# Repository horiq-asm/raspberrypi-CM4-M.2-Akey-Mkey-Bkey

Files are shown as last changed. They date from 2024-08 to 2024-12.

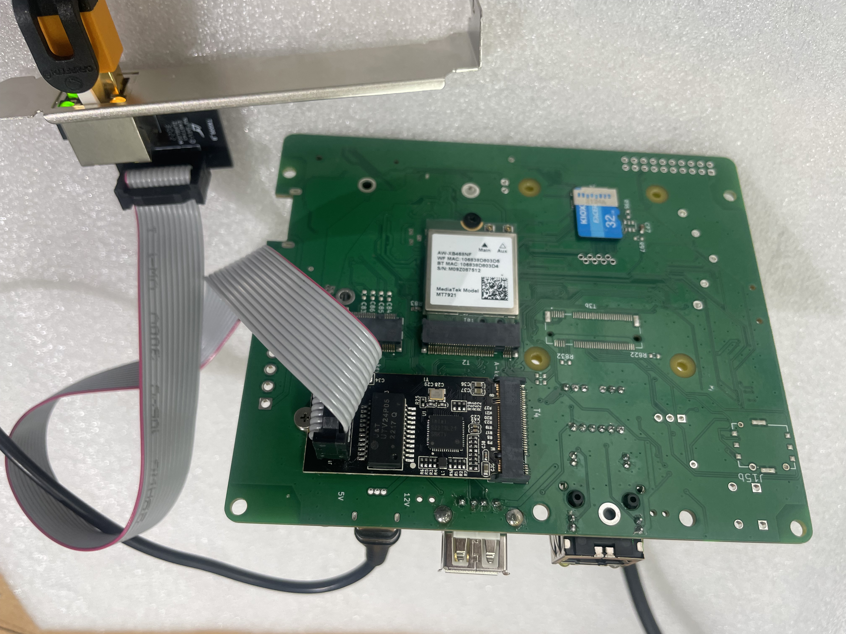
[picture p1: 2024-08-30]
IMG_6215.jpg

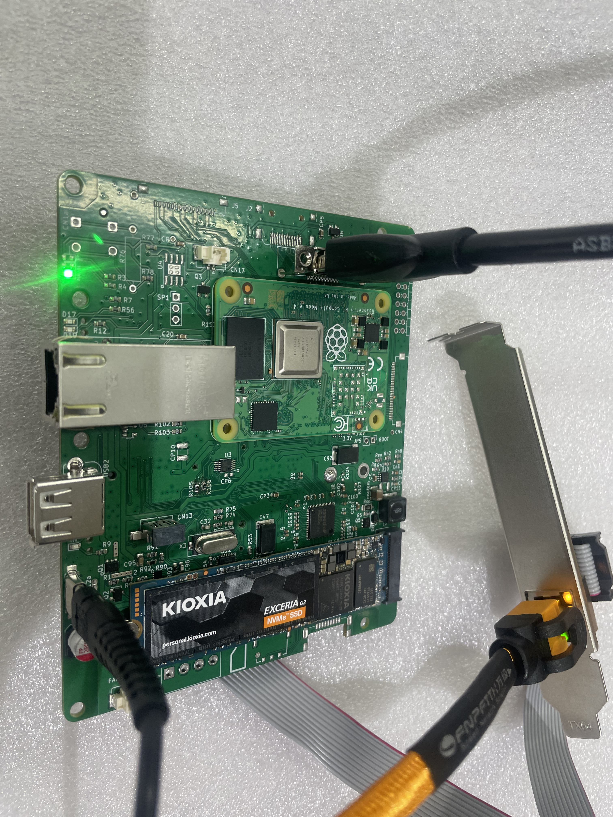
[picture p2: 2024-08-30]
IMG_6214.jpg

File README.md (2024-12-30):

boot CM5 via NVMe behind PCIe switch !!!<br>
新たに入手したCM5を入れるとNVMeからbootできました。
2024年12月クリスマスプレゼントです。<br>
youtube で動作画像ご覧ください　https://youtu.be/MDhNWYu6bRE



# raspberrypi-CM4-M.2-Akey-Mkey-Bkey
raspberypi　CM4にpcie swich を載せてM.2基板を複数動作できる基板を作成しました。
wifi6　１G　2.5Gのnicが動きます。
MkeyにはNVMeを搭載しています。

$ lspci<br>
00:00.0 PCI bridge: Broadcom Inc. and subsidiaries BCM2711 PCIe Bridge (rev 20)<br>
01:00.0 PCI bridge: ASMedia Technology Inc. ASM1184e 4-Port PCIe x1 Gen2 Packet Switch<br>
02:01.0 PCI bridge: ASMedia Technology Inc. ASM1184e 4-Port PCIe x1 Gen2 Packet Switch<br>
02:03.0 PCI bridge: ASMedia Technology Inc. ASM1184e 4-Port PCIe x1 Gen2 Packet Switch<br>
02:05.0 PCI bridge: ASMedia Technology Inc. ASM1184e 4-Port PCIe x1 Gen2 Packet Switch<br>
02:07.0 PCI bridge: ASMedia Technology Inc. ASM1184e 4-Port PCIe x1 Gen2 Packet Switch<br>
03:00.0 Network controller: MEDIATEK Corp. MT7921 802.11ax PCI Express Wireless Network Adapter<br>
04:00.0 Non-Volatile memory controller: KIOXIA Corporation NVMe SSD (rev 01)<br>
05:00.0 Ethernet controller: Intel Corporation Ethernet Controller I226-V (rev 04)<br>
<br>
$ ethtool eth1<br>
Settings for eth1:<br>
        Supported ports: [ TP ]<br>
        Supported link modes:   10baseT/Half 10baseT/Full<br>
                                100baseT/Half 100baseT/Full<br>
                                1000baseT/Full<br>
                                2500baseT/Full<br>
        Supported pause frame use: Symmetric<br>
        Supports auto-negotiation: Yes<br>
        Supported FEC modes: Not reported<br>
        Advertised link modes:  10baseT/Half 10baseT/Full<br>
                                100baseT/Half 100baseT/Full<br>
                                1000baseT/Full<br>
                                2500baseT/Full<br>
        Advertised pause frame use: Symmetric<br>
        Advertised auto-negotiation: Yes<br>
        Advertised FEC modes: Not reported<br>
        Speed: 2500Mb/s<br>
        Duplex: Full<br>
        Auto-negotiation: on<br>
        Port: Twisted Pair<br>
        PHYAD: 0<br>
        Transceiver: internal<br>
        MDI-X: off (auto)<br>
netlink error: Operation not permitted<br>
        Current message level: 0x00000007 (7)<br>
                               drv probe link<br>
        Link detected: yes<br>
<br>
<br>
$ nmcli d s<br>
DEVICE         TYPE      STATE                   CONNECTION<br>
wlan0          wifi      connected               WIFI_AP<br>
eth1           ethernet  connected               Wired connection 2<br>
lo             loopback  connected (externally)  lo<br>
p2p-dev-wlan0  wifi-p2p  disconnected            --<br>
eth0           ethernet  unavailable             --<br>
<br>
%%%<br>
Network controller: MEDIATEK Corp. MT7921 802.11ax PCI Express Wireless Network Adapter<br>
のためには　　/boot/firmware/config.txt　　に下記の変更が必要です。<br>
[all]<br>
dtparam=pciex1<br>
dtoverlay=pcie-32bit-dma<br>
<br>
<br>
$ iw phy0 info<br>
Wiphy phy0<br>
        wiphy index: 0<br>
        max # scan SSIDs: 4<br>
        max scan IEs length: 482 bytes<br>
        max # sched scan SSIDs: 10<br>
        max # match sets: 16<br>
        Retry short limit: 7<br>
        Retry long limit: 4<br>
        Coverage class: 0 (up to 0m)<br>
        Device supports AP-side u-APSD.<br>
        Device supports T-DLS.<br>
        Supported Ciphers:<br>
                * WEP40 (00-0f-ac:1)<br>
                * WEP104 (00-0f-ac:5)<br>
                * TKIP (00-0f-ac:2)<br>
                * CCMP-128 (00-0f-ac:4)<br>
                * CCMP-256 (00-0f-ac:10)<br>
                * GCMP-128 (00-0f-ac:8)<br>
                * GCMP-256 (00-0f-ac:9)<br>
                * CMAC (00-0f-ac:6)<br>
                * CMAC-256 (00-0f-ac:13)<br>
                * GMAC-128 (00-0f-ac:11)<br>
                * GMAC-256 (00-0f-ac:12)<br>
        Available Antennas: TX 0x3 RX 0x3<br>
        Configured Antennas: TX 0x3 RX 0x3<br>
        Supported interface modes:<br>
                 * managed<br>
                 * AP<br>
                 * AP/VLAN<br>
                 * monitor<br>
                 * P2P-client<br>
                 * P2P-GO<br>
        Band 1:<br>
                Capabilities: 0x9ff<br>
                        RX LDPC<br>
                        HT20/HT40<br>
                        SM Power Save disabled<br>
                        RX Greenfield<br>
                        RX HT20 SGI<br>
                        RX HT40 SGI<br>
                        TX STBC<br>
                        RX STBC 1-stream<br>
                        Max AMSDU length: 7935 bytes<br>
                        No DSSS/CCK HT40<br>
                Maximum RX AMPDU length 65535 bytes (exponent: 0x003)<br>
                Minimum RX AMPDU time spacing: No restriction (0x00)<br>
                HT TX/RX MCS rate indexes supported: 0-15<br>
                HE Iftypes: managed<br>
                        HE MAC Capabilities (0x08011a000040):<br>
                                +HTC HE Supported<br>
                                Trigger Frame MAC Padding Duration: 2<br>
                                OM Control<br>
                                Maximum A-MPDU Length Exponent: 3<br>
                                A-MSDU in A-MPDU<br>
                        HE PHY Capabilities: (0x2270ce120dc0b306423f00):<br>
                                HE40/2.4GHz<br>
                                242 tone RUs/2.4GHz<br>
                                Device Class: 1<br>
                                LDPC Coding in Payload<br>
                                HE SU PPDU with 1x HE-LTF and 0.8us GI<br>
                                NDP with 4x HE-LTF and 3.2us GI<br>
                                STBC Tx <= 80MHz<br>
                                STBC Rx <= 80MHz<br>
                                Full Bandwidth UL MU-MIMO<br>
                                Partial Bandwidth UL MU-MIMO<br>
                                DCM Max Constellation: 2<br>
                                DCM Max Constellation Rx: 2<br>
                                SU Beamformee<br>
                                Beamformee STS <= 80Mhz: 3<br>
                                Ng = 16 SU Feedback<br>
                                Ng = 16 MU Feedback<br>
                                Codebook Size SU Feedback<br>
                                Codebook Size MU Feedback<br>
                                Triggered CQI Feedback<br>
                                Partial Bandwidth Extended Range<br>
                                PPE Threshold Present<br>
                                Power Boost Factor ar<br>
                                HE SU PPDU & HE PPDU 4x HE-LTF 0.8us GI<br>
                                20MHz in 40MHz HE PPDU 2.4GHz<br>
                                DCM Max BW: 1<br>
                                Longer Than 16HE SIG-B OFDM Symbols<br>
                                Non-Triggered CQI Feedback<br>
                                TX 1024-QAM<br>
                                RX 1024-QAM<br>
                                RX Full BW SU Using HE MU PPDU with Compression SIGB<br>
                                RX Full BW SU Using HE MU PPDU with Non-Compression SIGB<br>
                        HE RX MCS and NSS set <= 80 MHz<br>
                                1 streams: MCS 0-11<br>
                                2 streams: MCS 0-11<br>
                                3 streams: not supported<br>
                                4 streams: not supported<br>
                                5 streams: not supported<br>
                                6 streams: not supported<br>
                                7 streams: not supported<br>
                                8 streams: not supported<br>
                        HE TX MCS and NSS set <= 80 MHz<br>
                                1 streams: MCS 0-11<br>
                                2 streams: MCS 0-11<br>
                                3 streams: not supported<br>
                                4 streams: not supported<br>
                                5 streams: not supported<br>
                                6 streams: not supported<br>
                                7 streams: not supported<br>
                                8 streams: not supported<br>
                        PPE Threshold 0x39 0x1c 0xc7 0x71 0x1c 0x07<br>
                EHT Iftypes: managed<br>
                        EHT MAC Capabilities (0x0000):<br>
                        EHT PHY Capabilities: (0x0000000000000000):<br>
                        EHT MCS/NSS: (0x):<br>
                        EHT bw=20 MHz, max NSS for MCS 0-7: Rx=0, Tx=0<br>
                        EHT bw=20 MHz, max NSS for MCS 8-9: Rx=0, Tx=0<br>
                        EHT bw=20 MHz, max NSS for MCS 10-11: Rx=0, Tx=0<br>
                        EHT bw=20 MHz, max NSS for MCS 12-13: Rx=0, Tx=0<br>
                HE Iftypes: AP<br>
                        HE MAC Capabilities (0x00011a081044):<br>
                                +HTC HE Supported<br>
                                BSR<br>
                                OM Control<br>
                                Maximum A-MPDU Length Exponent: 3<br>
                                BQR<br>
                                A-MSDU in A-MPDU<br>
                                OM Control UL MU Data Disable RX<br>
                        HE PHY Capabilities: (0x0220ce120000a000000c00):<br>
                                HE40/2.4GHz<br>
                                LDPC Coding in Payload<br>
                                NDP with 4x HE-LTF and 3.2us GI<br>
                                STBC Tx <= 80MHz<br>
                                STBC Rx <= 80MHz<br>
                                Full Bandwidth UL MU-MIMO<br>
                                Partial Bandwidth UL MU-MIMO<br>
                                DCM Max Constellation: 2<br>
                                DCM Max Constellation Rx: 2<br>
                                Partial Bandwidth Extended Range<br>
                                PPE Threshold Present<br>
                                TX 1024-QAM<br>
                                RX 1024-QAM<br>
                        HE RX MCS and NSS set <= 80 MHz<br>
                                1 streams: MCS 0-11<br>
                                2 streams: MCS 0-11<br>
                                3 streams: not supported<br>
                                4 streams: not supported<br>
                                5 streams: not supported<br>
                                6 streams: not supported<br>
                                7 streams: not supported<br>
                                8 streams: not supported<br>
                        HE TX MCS and NSS set <= 80 MHz<br>
                                1 streams: MCS 0-11<br>
                                2 streams: MCS 0-11<br>
                                3 streams: not supported<br>
                                4 streams: not supported<br>
                                5 streams: not supported<br>
                                6 streams: not supported<br>
                                7 streams: not supported<br>
                                8 streams: not supported<br>
                        PPE Threshold 0x39 0x1c 0xc7 0x71 0x1c 0x07<br>
                EHT Iftypes: AP<br>
                        EHT MAC Capabilities (0x0000):<br>
                        EHT PHY Capabilities: (0x0000000000000000):<br>
                        EHT MCS/NSS: (0x):<br>
                        EHT bw=20 MHz, max NSS for MCS 0-7: Rx=0, Tx=0<br>
                        EHT bw=20 MHz, max NSS for MCS 8-9: Rx=0, Tx=0<br>
                        EHT bw=20 MHz, max NSS for MCS 10-11: Rx=0, Tx=0<br>
                        EHT bw=20 MHz, max NSS for MCS 12-13: Rx=0, Tx=0<br>
                Bitrates (non-HT):<br>
                        * 1.0 Mbps (short preamble supported)<br>
                        * 2.0 Mbps (short preamble supported)<br>
                        * 5.5 Mbps (short preamble supported)<br>
                        * 11.0 Mbps (short preamble supported)<br>
                        * 6.0 Mbps<br>
                        * 9.0 Mbps<br>
                        * 12.0 Mbps<br>
                        * 18.0 Mbps<br>
                        * 24.0 Mbps<br>
                        * 36.0 Mbps<br>
                        * 48.0 Mbps<br>
                        * 54.0 Mbps<br>
                Frequencies:<br>
                        * 2412 MHz [1] (20.0 dBm)<br>
                        * 2417 MHz [2] (20.0 dBm)<br>
                        * 2422 MHz [3] (20.0 dBm)<br>
                        * 2427 MHz [4] (20.0 dBm)<br>
                        * 2432 MHz [5] (20.0 dBm)<br>
                        * 2437 MHz [6] (20.0 dBm)<br>
                        * 2442 MHz [7] (20.0 dBm)<br>
                        * 2447 MHz [8] (20.0 dBm)<br>
                        * 2452 MHz [9] (20.0 dBm)<br>
                        * 2457 MHz [10] (20.0 dBm)<br>
                        * 2462 MHz [11] (20.0 dBm)<br>
                        * 2467 MHz [12] (20.0 dBm)<br>
                        * 2472 MHz [13] (20.0 dBm)<br>
                        * 2484 MHz [14] (20.0 dBm)<br>
        Band 2:<br>
                Capabilities: 0x9ff<br>
                        RX LDPC<br>
                        HT20/HT40<br>
                        SM Power Save disabled<br>
                        RX Greenfield<br>
                        RX HT20 SGI<br>
                        RX HT40 SGI<br>
                        TX STBC<br>
                        RX STBC 1-stream<br>
                        Max AMSDU length: 7935 bytes<br>
                        No DSSS/CCK HT40<br>
                Maximum RX AMPDU length 65535 bytes (exponent: 0x003)<br>
                Minimum RX AMPDU time spacing: No restriction (0x00)<br>
                HT TX/RX MCS rate indexes supported: 0-15<br>
                VHT Capabilities (0x339071b2):<br>
                        Max MPDU length: 11454<br>
                        Supported Channel Width: neither 160 nor 80+80<br>
                        RX LDPC<br>
                        short GI (80 MHz)<br>
                        TX STBC<br>
                        SU Beamformee<br>
                        MU Beamformee<br>
                        RX antenna pattern consistency<br>
                        TX antenna pattern consistency<br>
                VHT RX MCS set:<br>
                        1 streams: MCS 0-9<br>
                        2 streams: MCS 0-9<br>
                        3 streams: not supported<br>
                        4 streams: not supported<br>
                        5 streams: not supported<br>
                        6 streams: not supported<br>
                        7 streams: not supported<br>
                        8 streams: not supported<br>
                VHT RX highest supported: 0 Mbps<br>
                VHT TX MCS set:<br>
                        1 streams: MCS 0-9<br>
                        2 streams: MCS 0-9<br>
                        3 streams: not supported<br>
                        4 streams: not supported<br>
                        5 streams: not supported<br>
                        6 streams: not supported<br>
                        7 streams: not supported<br>
                        8 streams: not supported<br>
                VHT TX highest supported: 0 Mbps<br>
                VHT extended NSS: supported<br>
                HE Iftypes: managed<br>
                        HE MAC Capabilities (0x08011a000040):<br>
                                +HTC HE Supported<br>
                                Trigger Frame MAC Padding Duration: 2<br>
                                OM Control<br>
                                Maximum A-MPDU Length Exponent: 3<br>
                                A-MSDU in A-MPDU<br>
                        HE PHY Capabilities: (0x4470ce120dc0b306423f00):<br>
                                HE40/HE80/5GHz<br>
                                242 tone RUs/5GHz<br>
                                Device Class: 1<br>
                                LDPC Coding in Payload<br>
                                HE SU PPDU with 1x HE-LTF and 0.8us GI<br>
                                NDP with 4x HE-LTF and 3.2us GI<br>
                                STBC Tx <= 80MHz<br>
                                STBC Rx <= 80MHz<br>
                                Full Bandwidth UL MU-MIMO<br>
                                Partial Bandwidth UL MU-MIMO<br>
                                DCM Max Constellation: 2<br>
                                DCM Max Constellation Rx: 2<br>
                                SU Beamformee<br>
                                Beamformee STS <= 80Mhz: 3<br>
                                Ng = 16 SU Feedback<br>
                                Ng = 16 MU Feedback<br>
                                Codebook Size SU Feedback<br>
                                Codebook Size MU Feedback<br>
                                Triggered CQI Feedback<br>
                                Partial Bandwidth Extended Range<br>
                                PPE Threshold Present<br>
                                Power Boost Factor ar<br>
                                HE SU PPDU & HE PPDU 4x HE-LTF 0.8us GI<br>
                                20MHz in 40MHz HE PPDU 2.4GHz<br>
                                DCM Max BW: 1<br>
                                Longer Than 16HE SIG-B OFDM Symbols<br>
                                Non-Triggered CQI Feedback<br>
                                TX 1024-QAM<br>
                                RX 1024-QAM<br>
                                RX Full BW SU Using HE MU PPDU with Compression SIGB<br>
                                RX Full BW SU Using HE MU PPDU with Non-Compression SIGB<br>
                        HE RX MCS and NSS set <= 80 MHz<br>
                                1 streams: MCS 0-11<br>
                                2 streams: MCS 0-11<br>
                                3 streams: not supported<br>
                                4 streams: not supported<br>
                                5 streams: not supported<br>
                                6 streams: not supported<br>
                                7 streams: not supported<br>
                                8 streams: not supported<br>
                        HE TX MCS and NSS set <= 80 MHz<br>
                                1 streams: MCS 0-11<br>
                                2 streams: MCS 0-11<br>
                                3 streams: not supported<br>
                                4 streams: not supported<br>
                                5 streams: not supported<br>
                                6 streams: not supported<br>
                                7 streams: not supported<br>
                                8 streams: not supported<br>
                        PPE Threshold 0x39 0x1c 0xc7 0x71 0x1c 0x07<br>
                EHT Iftypes: managed<br>
                        EHT MAC Capabilities (0x0000):<br>
                        EHT PHY Capabilities: (0x0000000000000000):<br>
                        EHT MCS/NSS: (0x):<br>
                        EHT bw <= 80 MHz, max NSS for MCS 8-9: Rx=0, Tx=0<br>
                        EHT bw <= 80 MHz, max NSS for MCS 10-11: Rx=0, Tx=0<br>
                        EHT bw <= 80 MHz, max NSS for MCS 12-13: Rx=0, Tx=0<br>
                HE Iftypes: AP<br>
                        HE MAC Capabilities (0x00011a081044):<br>
                                +HTC HE Supported<br>
                                BSR<br>
                                OM Control<br>
                                Maximum A-MPDU Length Exponent: 3<br>
                                BQR<br>
                                A-MSDU in A-MPDU<br>
                                OM Control UL MU Data Disable RX<br>
                        HE PHY Capabilities: (0x0420ce120000a000000c00):<br>
                                HE40/HE80/5GHz<br>
                                LDPC Coding in Payload<br>
                                NDP with 4x HE-LTF and 3.2us GI<br>
                                STBC Tx <= 80MHz<br>
                                STBC Rx <= 80MHz<br>
                                Full Bandwidth UL MU-MIMO<br>
                                Partial Bandwidth UL MU-MIMO<br>
                                DCM Max Constellation: 2<br>
                                DCM Max Constellation Rx: 2<br>
                                Partial Bandwidth Extended Range<br>
                                PPE Threshold Present<br>
                                TX 1024-QAM<br>
                                RX 1024-QAM<br>
                        HE RX MCS and NSS set <= 80 MHz<br>
                                1 streams: MCS 0-11<br>
                                2 streams: MCS 0-11<br>
                                3 streams: not supported<br>
                                4 streams: not supported<br>
                                5 streams: not supported<br>
                                6 streams: not supported<br>
                                7 streams: not supported<br>
                                8 streams: not supported<br>
                        HE TX MCS and NSS set <= 80 MHz<br>
                                1 streams: MCS 0-11<br>
                                2 streams: MCS 0-11<br>
                                3 streams: not supported<br>
                                4 streams: not supported<br>
                                5 streams: not supported<br>
                                6 streams: not supported<br>
                                7 streams: not supported<br>
                                8 streams: not supported<br>
                        PPE Threshold 0x39 0x1c 0xc7 0x71 0x1c 0x07<br>
                EHT Iftypes: AP<br>
                        EHT MAC Capabilities (0x0000):<br>
                        EHT PHY Capabilities: (0x0000000000000000):<br>
                        EHT MCS/NSS: (0x):<br>
                        EHT bw <= 80 MHz, max NSS for MCS 8-9: Rx=0, Tx=0<br>
                        EHT bw <= 80 MHz, max NSS for MCS 10-11: Rx=0, Tx=0<br>
                        EHT bw <= 80 MHz, max NSS for MCS 12-13: Rx=0, Tx=0<br>
                Bitrates (non-HT):<br>
                        * 6.0 Mbps<br>
                        * 9.0 Mbps<br>
                        * 12.0 Mbps<br>
                        * 18.0 Mbps<br>
                        * 24.0 Mbps<br>
                        * 36.0 Mbps<br>
                        * 48.0 Mbps<br>
                        * 54.0 Mbps<br>
                Frequencies:<br>
                        * 5180 MHz [36] (20.0 dBm)<br>
                        * 5200 MHz [40] (20.0 dBm)<br>
                        * 5220 MHz [44] (20.0 dBm)<br>
                        * 5240 MHz [48] (20.0 dBm)<br>
                        * 5260 MHz [52] (20.0 dBm) (radar detection)<br>
                        * 5280 MHz [56] (20.0 dBm) (radar detection)<br>
                        * 5300 MHz [60] (20.0 dBm) (radar detection)<br>
                        * 5320 MHz [64] (20.0 dBm) (radar detection)<br>
                        * 5500 MHz [100] (23.0 dBm) (radar detection)<br>
                        * 5520 MHz [104] (23.0 dBm) (radar detection)<br>
                        * 5540 MHz [108] (23.0 dBm) (radar detection)<br>
                        * 5560 MHz [112] (23.0 dBm) (radar detection)<br>
                        * 5580 MHz [116] (23.0 dBm) (radar detection)<br>
                        * 5600 MHz [120] (23.0 dBm) (radar detection)<br>
                        * 5620 MHz [124] (23.0 dBm) (radar detection)<br>
                        * 5640 MHz [128] (23.0 dBm) (radar detection)<br>
                        * 5660 MHz [132] (23.0 dBm) (radar detection)<br>
                        * 5680 MHz [136] (23.0 dBm) (radar detection)<br>
                        * 5700 MHz [140] (23.0 dBm) (radar detection)<br>
                        * 5720 MHz [144] (disabled)<br>
                        * 5745 MHz [149] (disabled)<br>
                        * 5765 MHz [153] (disabled)<br>
                        * 5785 MHz [157] (disabled)<br>
                        * 5805 MHz [161] (disabled)<br>
                        * 5825 MHz [165] (disabled)<br>
                        * 5845 MHz [169] (disabled)<br>
                        * 5865 MHz [173] (disabled)<br>
                        * 5885 MHz [177] (disabled)<br>
        Supported commands:<br>
                 * new_interface<br>
                 * set_interface<br>
                 * new_key<br>
                 * start_ap<br>
                 * new_station<br>
                 * new_mpath<br>
                 * set_mesh_config<br>
                 * set_bss<br>
                 * authenticate<br>
                 * associate<br>
                 * deauthenticate<br>
                 * disassociate<br>
                 * join_ibss<br>
                 * join_mesh<br>
                 * remain_on_channel<br>
                 * set_tx_bitrate_mask<br>
                 * frame<br>
                 * frame_wait_cancel<br>
                 * set_wiphy_netns<br>
                 * set_channel<br>
                 * tdls_mgmt<br>
                 * tdls_oper<br>
                 * start_sched_scan<br>
                 * probe_client<br>
                 * set_noack_map<br>
                 * register_beacons<br>
                 * start_p2p_device<br>
                 * set_mcast_rate<br>
                 * connect<br>
                 * disconnect<br>
                 * channel_switch<br>
                 * set_qos_map<br>
                 * set_multicast_to_unicast<br>
                 * set_sar_specs<br>
        WoWLAN support:<br>
                 * wake up on disconnect<br>
                 * wake up on magic packet<br>
                 * wake up on pattern match, up to 1 patterns of 1-128 bytes,<br>
                   maximum packet offset 0 bytes<br>
                 * can do GTK rekeying<br>
                 * wake up on network detection, up to 10 match sets<br>
        software interface modes (can always be added):<br>
                 * AP/VLAN<br>
                 * monitor<br>
        valid interface combinations:<br>
                 * #{ managed, P2P-client } <= 2, #{ AP, P2P-GO } <= 1,<br>
                   total <= 2, #channels <= 2<br>
        HT Capability overrides:<br>
                 * MCS: ff ff ff ff ff ff ff ff ff ff<br>
                 * maximum A-MSDU length<br>
                 * supported channel width<br>
                 * short GI for 40 MHz<br>
                 * max A-MPDU length exponent<br>
                 * min MPDU start spacing<br>
        Device supports TX status socket option.<br>
        Device supports HT-IBSS.<br>
        Device supports SAE with AUTHENTICATE command<br>
        Device supports scan flush.<br>
        Device supports per-vif TX power setting<br>
        Driver supports full state transitions for AP/GO clients<br>
        Driver supports a userspace MPM<br>
        Device supports active monitor (which will ACK incoming frames)<br>
        Driver/device bandwidth changes during BSS lifetime (AP/GO mode)<br>
        Device supports configuring vdev MAC-addr on create.<br>
        Device supports randomizing MAC-addr in scans.<br>
        Device supports randomizing MAC-addr in sched scans.<br>
        max # scan plans: 1<br>
        max scan plan interval: 65535<br>
        max scan plan iterations: 0<br>
        Supported TX frame types:<br>
                 * IBSS: 0x00 0x10 0x20 0x30 0x40 0x50 0x60 0x70 0x80 0x90 0xa0 0xb0 0xc0 0xd0 0xe0 0xf0<br>
                 * managed: 0x00 0x10 0x20 0x30 0x40 0x50 0x60 0x70 0x80 0x90 0xa0 0xb0 0xc0 0xd0 0xe0 0xf0<br>
                 * AP: 0x00 0x10 0x20 0x30 0x40 0x50 0x60 0x70 0x80 0x90 0xa0 0xb0 0xc0 0xd0 0xe0 0xf0<br>
                 * AP/VLAN: 0x00 0x10 0x20 0x30 0x40 0x50 0x60 0x70 0x80 0x90 0xa0 0xb0 0xc0 0xd0 0xe0 0xf0<br>
                 * mesh point: 0x00 0x10 0x20 0x30 0x40 0x50 0x60 0x70 0x80 0x90 0xa0 0xb0 0xc0 0xd0 0xe0 0xf0<br>
                 * P2P-client: 0x00 0x10 0x20 0x30 0x40 0x50 0x60 0x70 0x80 0x90 0xa0 0xb0 0xc0 0xd0 0xe0 0xf0<br>
                 * P2P-GO: 0x00 0x10 0x20 0x30 0x40 0x50 0x60 0x70 0x80 0x90 0xa0 0xb0 0xc0 0xd0 0xe0 0xf0<br>
                 * P2P-device: 0x00 0x10 0x20 0x30 0x40 0x50 0x60 0x70 0x80 0x90 0xa0 0xb0 0xc0 0xd0 0xe0 0xf0<br>
        Supported RX frame types:<br>
                 * IBSS: 0x40 0xb0 0xc0 0xd0<br>
                 * managed: 0x40 0xb0 0xd0<br>
                 * AP: 0x00 0x20 0x40 0xa0 0xb0 0xc0 0xd0<br>
                 * AP/VLAN: 0x00 0x20 0x40 0xa0 0xb0 0xc0 0xd0<br>
                 * mesh point: 0xb0 0xc0 0xd0<br>
                 * P2P-client: 0x40 0xd0<br>
                 * P2P-GO: 0x00 0x20 0x40 0xa0 0xb0 0xc0 0xd0<br>
                 * P2P-device: 0x40 0xd0<br>
        Supported extended features:<br>
                * [ RRM ]: RRM<br>
                * [ SET_SCAN_DWELL ]: scan dwell setting<br>
                * [ BEACON_RATE_LEGACY ]: legacy beacon rate setting<br>
                * [ BEACON_RATE_HT ]: HT beacon rate setting<br>
                * [ BEACON_RATE_VHT ]: VHT beacon rate setting<br>
                * [ FILS_STA ]: STA FILS (Fast Initial Link Setup)<br>
                * [ CQM_RSSI_LIST ]: multiple CQM_RSSI_THOLD records<br>
                * [ CONTROL_PORT_OVER_NL80211 ]: control port over nl80211<br>
                * [ ACK_SIGNAL_SUPPORT ]: ack signal level support<br>
                * [ TXQS ]: FQ-CoDel-enabled intermediate TXQs<br>
                * [ CAN_REPLACE_PTK0 ]: can safely replace PTK 0 when rekeying<br>
                * [ AIRTIME_FAIRNESS ]: airtime fairness scheduling<br>
                * [ AQL ]: Airtime Queue Limits (AQL)<br>
                * [ CONTROL_PORT_NO_PREAUTH ]: disable pre-auth over nl80211 control port support<br>
                * [ SCAN_FREQ_KHZ ]: scan on kHz frequency support<br>
                * [ CONTROL_PORT_OVER_NL80211_TX_STATUS ]: tx status for nl80211 control port support<br>
                * [ BEACON_RATE_HE ]: HE beacon rate support (AP/mesh)<br>

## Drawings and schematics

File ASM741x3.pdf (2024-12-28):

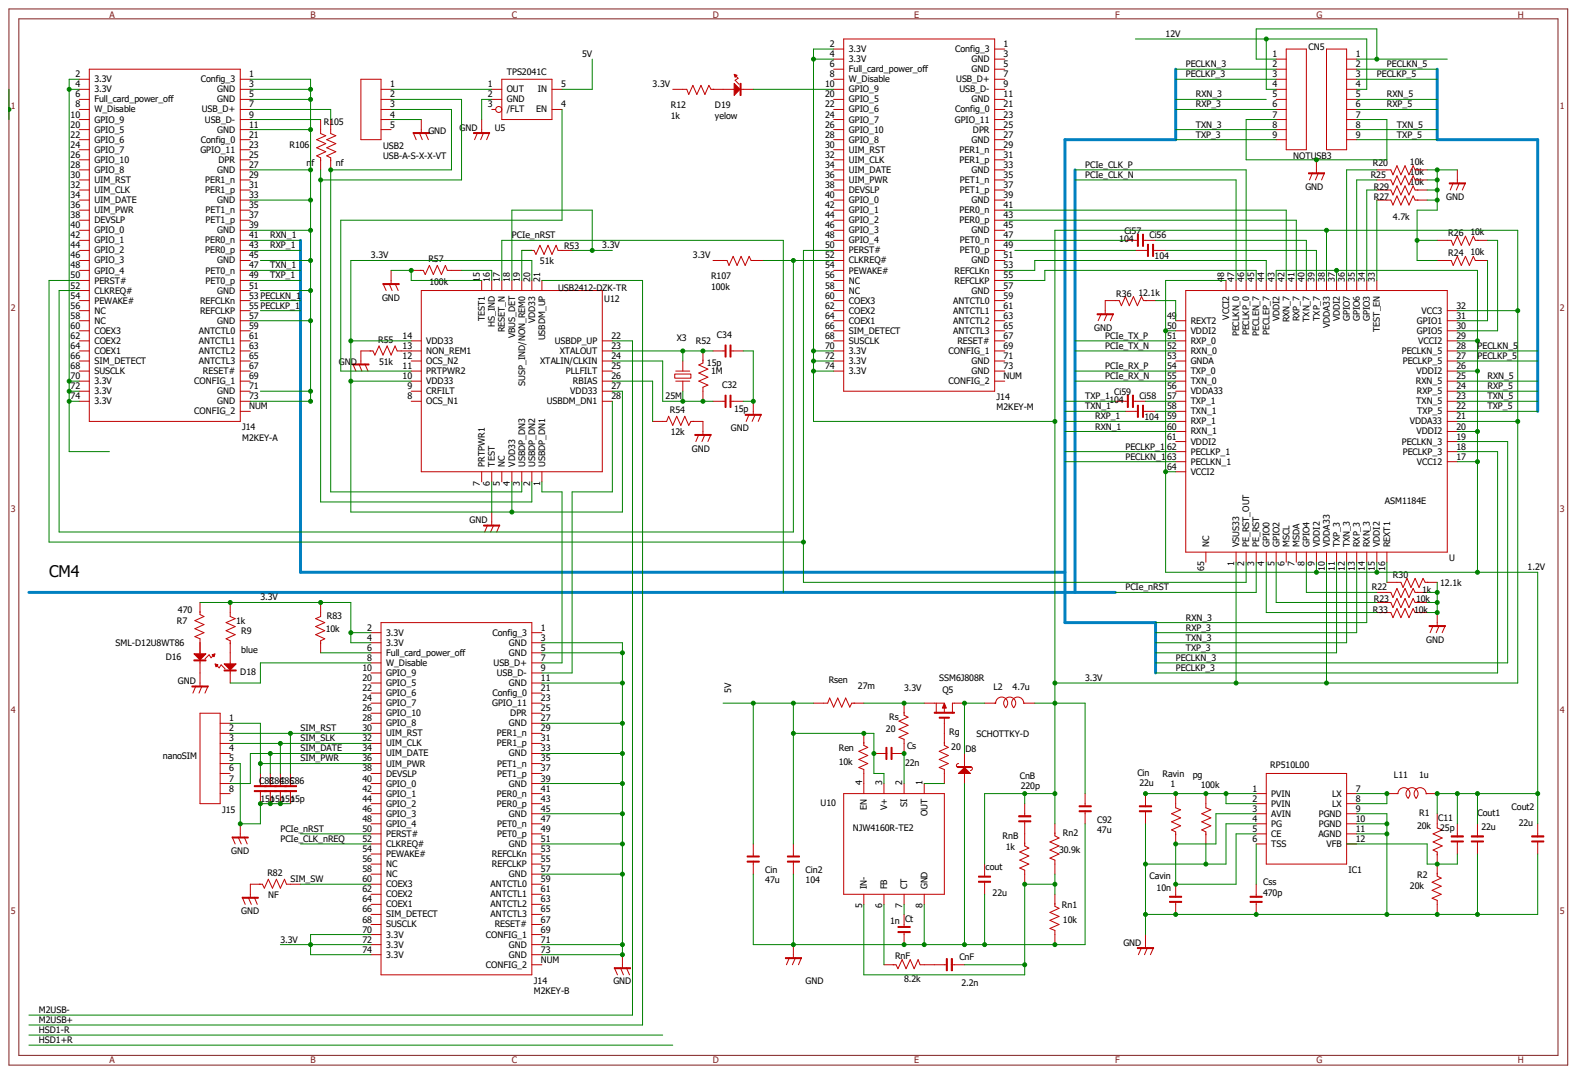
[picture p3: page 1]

32 TEST_EN ³³ GPIO³ ³⁴ GPIO⁶ ³⁵ GPIO⁷ ³⁶ VDDI2 37 VDDA³³ ³⁸ TXP_7 39 TXN_7 40 RXP_7 41 RXN_7 42 VDDI2 43 PECLEP_7 44 PECLEN_7 45 PECLKP_0 46 PECLKN_0 47 VCCI2 48

VDDI2 50 | 30
RXP_0 51 | 29 | PECLKN_5

RXP_1 | 104 | | RXP_1 59 | 21 | 1.2V
RXN_1 | | | RXN_1 60 | 20
PECLKP_1 | | | VDDI2 61 | 19
PECLKN_1 | | PECLKN_1 63 | 17

PECLKP_1 62 | 18

3 | SIM_SLK | UIM_CLK 32
4 | | SIM_DATE | UIM_DATE 34

SIM_PWR | UIM_PWR 36

PG 4 | 10
CE 5 | 11

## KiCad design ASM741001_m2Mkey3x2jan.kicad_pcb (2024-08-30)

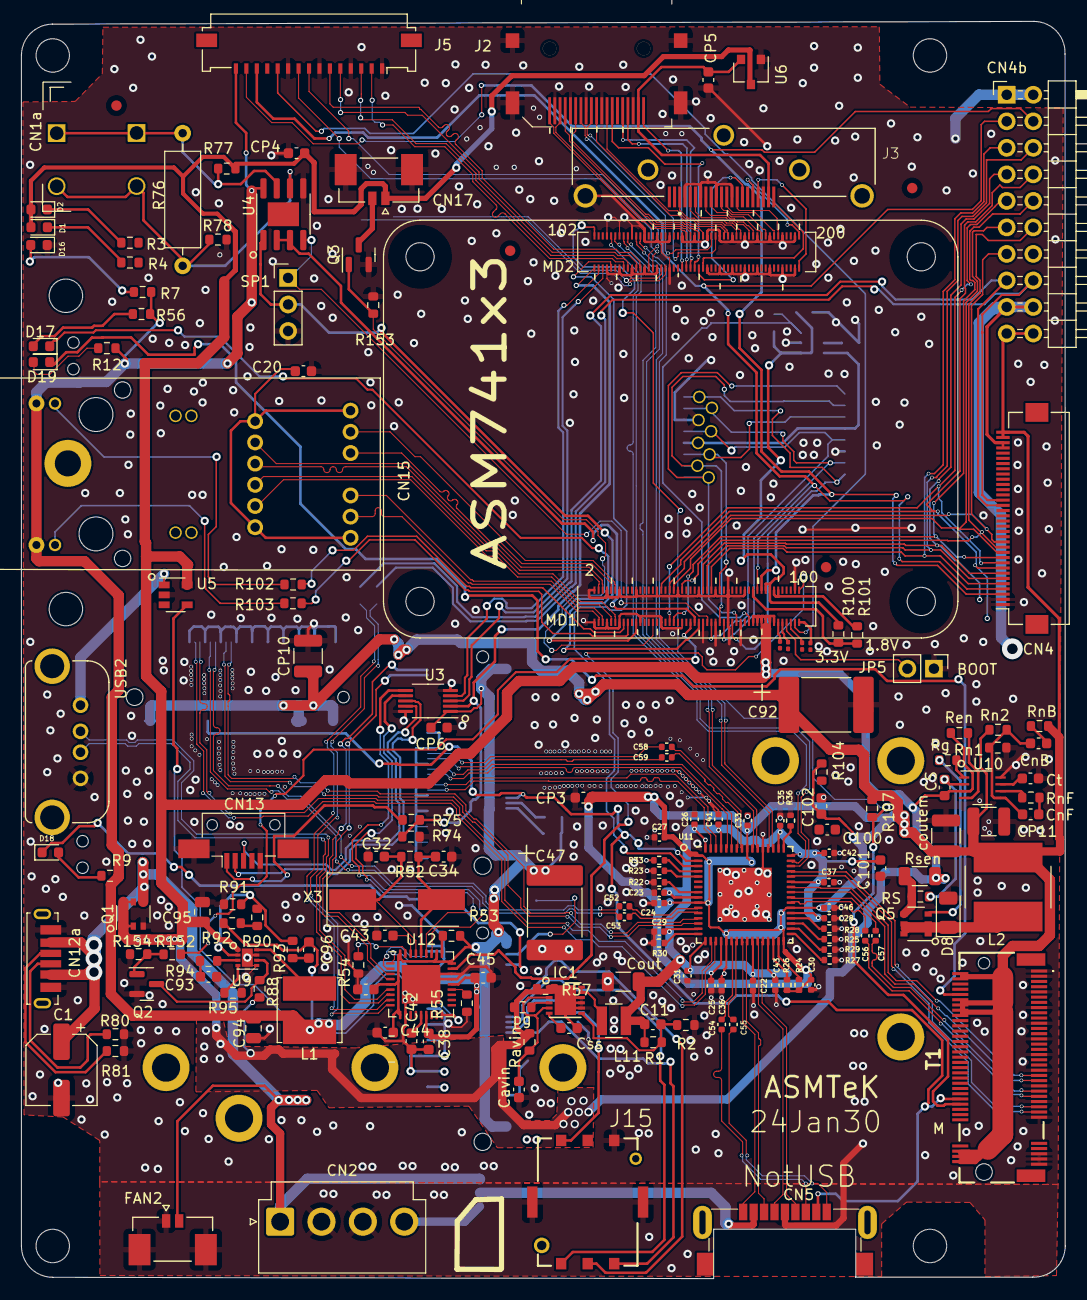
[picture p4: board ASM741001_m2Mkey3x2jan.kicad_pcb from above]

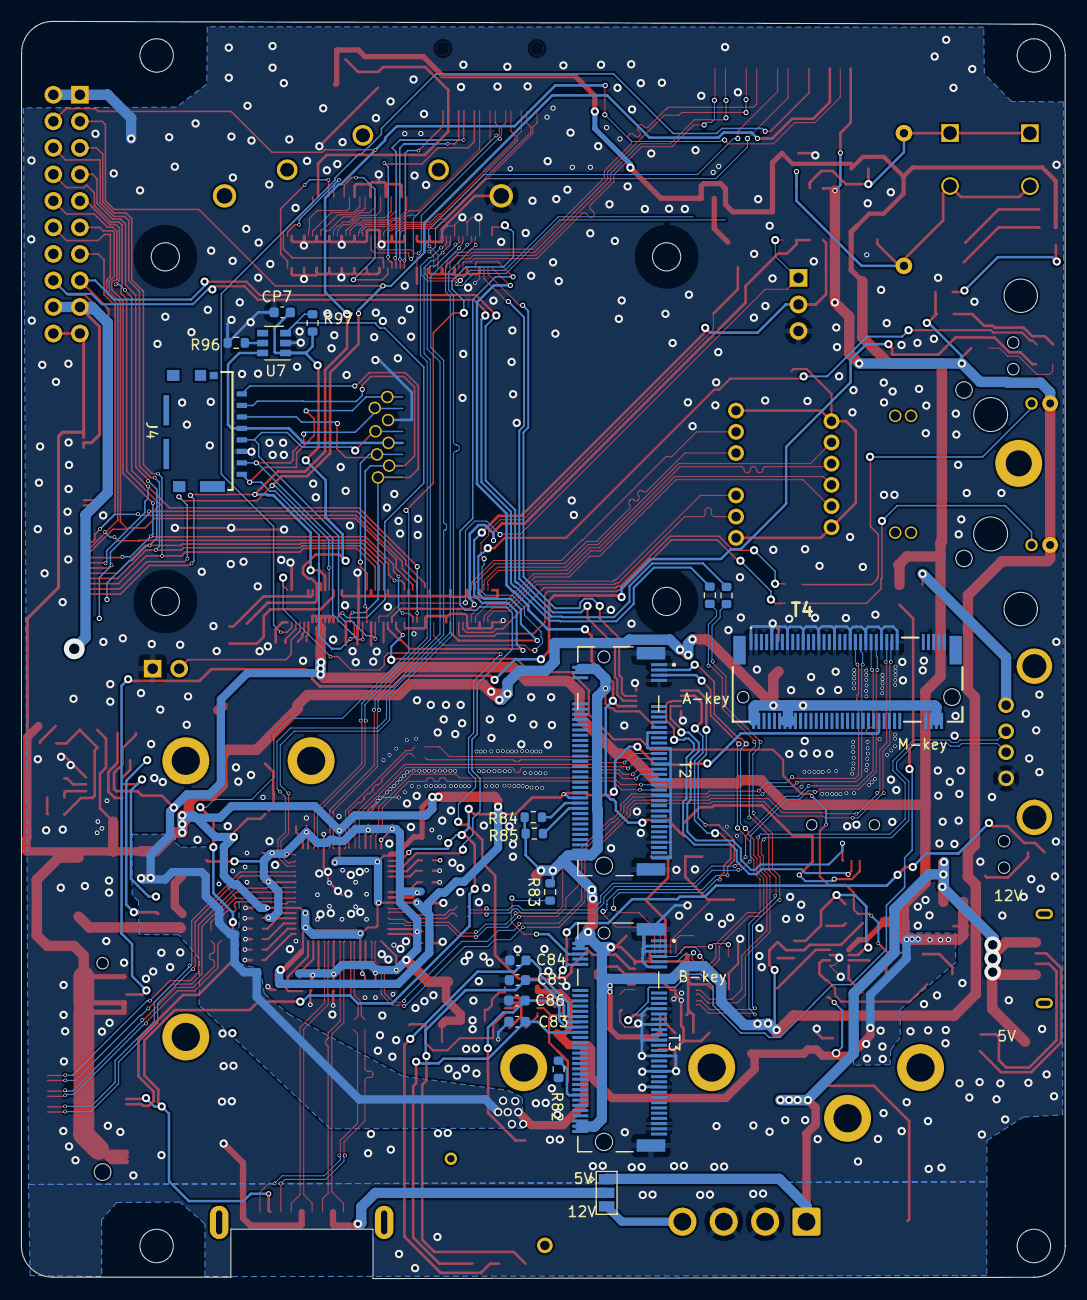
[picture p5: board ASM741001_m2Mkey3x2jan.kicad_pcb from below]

Board: 2 copper layers, 100.0 x 120.4 mm, 192 parts (18 on the bottom side), 211 nets.

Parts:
C1: RSA0J331MCN1GS; CP_Elec_6.3x5.8
C2, C42#2, C43, C44, C45: 104; C_0603_1608Metric
C11: 25p; C_0603_1608Metric
C20: 0.1u/25v; C_0603_1608Metric
C22, C23, C24, C25, C26, C27, C28, C29, C30, C31, C33, C35, C36, C37, C41, C42, C43#2, C46, C52, C53, C54, C55, C56, C57, C58, C59: 100nF; C_0402_1005Metric
C32, C34, C96: 15ｐ; C_0603_1608Metric
C38: 4.7u; C_0603_1608Metric
C47, C92: ECASD40J476M025K00; C_2220_5650Metric_Pad1.97x5.40mm_HandSolder
C83, C84, C85, C86: C:2; C_0603_1608Metric
C93: 10ｐ; C_0603_1608Metric
C94, C95: GRM188R61C106MAALD; C_0805_2012Metric
C100, C102: C_0603_1608Metric
C101: 100n; C_0603_1608Metric
CN1a: TB411-2-2-E-1; PinHeader_1x02_P2.54mm_Vertical
CN2: JST_VH_B4P-VH_1x04_P3.96mm_Vertical
CN4: CN:27; Hirose_FH12-34S-0.5SH_1x34-1MP_P0.50mm_Horizontal
CN4b: PinHeader_2x10_P2.54mm_Horizontal
CN5: USB_A_Female_AU-Y1006-3
CN12a: CUI_UJC-VP-3-SMT-TR
CN13: CN:5; USB_Mini-B_AdamTech_MUSB-B5-S-VT-TSMT-1_SMD_Vertical
CN15: 0838-1x1t-w7
CN17: MOLEX_533980271
CP3, CP4, CP5, CP6, CP7: 104; C_0603_1608Metric
CP10, CP11: C_1210_3225Metric
CS: 22n; C_0603_1608Metric
Cavin: 10n; C_0603_1608Metric
CnB: 220p; C_0603_1608Metric
CnF: 2.2n; C_0603_1608Metric
Cout: 22u; C_1206_3216Metric
Css: 470p; C_0603_1608Metric
Ct: 1n; C_0603_1608Metric
D1, D16: green; LED_0603_1608Metric
D2, D17: red; LED_0603_1608Metric
D8: D_1206_3216Metric
D18: blue; LED_0603_1608Metric
D19: yelow; LED_0603_1608Metric
FAN2: MOLEX_533980271
IC1: RP510L00; DFN-12-1EP_3x3mm_P0.5mm_EP2.05x2.86mm
J2: HDMI_A_Female_2000-1-2-41-00-BK; HDMI
J3: SS-53000-003; BEL_SS-53000-003
J4: 105162-0001
J5: 0522711579; Molex_200528-0150_1x15-1MP_P1.00mm_Horizontal
J15: GCT_SIM8051-6-0-14-01-X-REVD
JP1, JP2, JP3, JP4: nf; R_0201_0603Metric
JP5: PinHeader_1x02_P2.54mm_Vertical
L1: SRN6045TA-4R7M; L_Bourns_SRN6045TA
L2: SRN6045TA-4R7M; L_Bourns_SRN8040TA
L11: 1u; L_Abracon_ASPI-3012S
Module1: ComputeModule4; Raspberry-Pi-4-Compute-Module
Q1, Q5: SSM6J808R; TSOP-6_1.65x3.05mm_P0.95mm
Q2, Q3: BSS138-TP; SOT-23
R1, R2: 20k; R_0603_1608Metric
R3, R4, R9, R12, R56, R77, R78, R82, R153: 1k; R_0603_1608Metric
R7: 4.7k; R_0603_1608Metric
R22, R23, R25, R27: 1K; R_0402_1005Metric
R24, R26, R28, R29, R33: 10K; R_0402_1005Metric
R30, R36: 12.1K; R_0402_1005Metric
R52: 1M; R_0603_1608Metric
R53, R55, R57: 51k; R_0603_1608Metric
R54, R91: 12k; R_0603_1608Metric
R74, R75, R88: 2.2k; R_0603_1608Metric
R76: 680 1/2w; R_Axial_DIN0309_L9.0mm_D3.2mm_P12.70mm_Horizontal
R80, R81, R95: 5.1k; R_0603_1608Metric
R83, R84, R85, R94, R154: 10k; R_0603_1608Metric
R90: 3.9k; R_0603_1608Metric
R92: ERJ-3EKF5102V; R_0603_1608Metric
R93: 0k; R_0603_1608Metric
R96, R97: 2.2ｋ; R_0603_1608Metric
R100, R101: R:2; R_0603_1608Metric
R102, R103: 1ｋ; R_0603_1608Metric
R104: R_0603_1608Metric
R105x, R106x, R152: 0; R_0603_1608Metric
R107: 100k; R_0603_1608Metric
RS: 20; R_0603_1608Metric
Ravin: 1; R_0603_1608Metric
Ren: 10k; R_0603_1608Metric
Rg: 20; R_0603_1608Metric
Rn1: 10k; R_0603_1608Metric
Rn2: 30.9k; R_0603_1608Metric
RnB: 1k; R_0603_1608Metric
RnF: 8.2k; R_0603_1608Metric
Rsen: 27m; R_1206_3216Metric
SP1: PinHeader_1x03_P2.54mm_Vertical
T1: 1-2199230-5; MDT420M01001
T2: 2199230-8; b9973afb-34f9-4941-8c1f-dffebdb6dde0
T3: 2199230-3; b9973afb-34f9-4941-8c1f-dffebdb6dde0
T4: MDT420M01001
U3: FSUSB42MUX; MSOP-10-1EP_3x3mm_P0.5mm_EP1.68x1.88mm_ThermalVias
U4: THVD1419; SOIC-8-1EP_3.9x4.9mm_P1.27mm_EP2.29x3mm
U5: TPS2041C; SOT-23-5
U6: AP2331W; SC-59
U7: BD2222G; SOT-23-6
U9: NJW4122KU1-TE3; DFN-8-1EP_2x2mm_P0.5mm_EP1.05x1.75mm
U10: NJW4160R-TE2; SOT-23-8_Handsoldering
U11: ASM1184e; QFN-64-1EP_9x9mm_P0.5mm_EP5.2x5.2mm
U12: USB2514BI-AEZG-TR; QFN-36-1EP_6x6mm_P0.5mm_EP3.7x3.7mm
USB2: USB-A-S-X-X-VT
X3: 24M; Crystal_SMD_HC49-SD
coutem: C_1210_3225Metric
h2, h2#2, h2#3, h10, h15, h15#2: MountingHole_3.2mm_M3
h4, h4#2, h5, h5#2: MountingHole_1.1mm; MountingHole_2.1mm
pg: 100k; R_0603_1608Metric

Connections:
1.8V: Module1.88 (+1.8v_(Output)), Module1.90 (+1.8v_(Output)), R101.1
1v2: C11.2, C22.1, C23.1, C25.1, C26.1, C28.1, C29.1, C31.1, C35.1, C37.1, C41.1, C42.1, C43#2.1, C101.2, Cout.1, L11.2, R1.2, U11.9 (1V2), U11.15 (1V2), U11.17 (1V2), U11.20 (1V2), U11.26 (1V2), U11.29 (1V2), U11.37 (1V2), U11.43 (1V2), U11.48 (1V2), U11.50 (1V2), U11.61 (1V2), U11.64 (1V2)
3.3V: C2.1, C38.2, C44.1, C45.2, C47.2, C94.2, C96.1, CN15.18, CN15.20, CP6.1, J5.15, L1.1, R7.2, R9.1, R12.2, R53.1, R56.2, R83.2, R84.1, R85.1, R92.1, T2.2, T2.4, T2.72, T2.74, T3.2, T3.4, T3.70, T3.72, T3.74, U3.1, U4.8, U12.5, U12.10, U12.15, U12.23, U12.27, U12.29, U12.36
3.3vem: C24.1, C27.1, C30.1, C33.1, C36.1, C46.1, C92.1, C102.1, CN4.33, CN4.34, CN4b.19, CN4b.20, CP3.2, CP10.1, CP11.2, L2.2, R24.1, R26.1, R104.2, R107.2, Rn2.1, RnB.1, T1.2, T1.4, T1.12, T1.14, T1.16, T1.18, T1.70, T1.72, T1.74, T4.2, T4.4, T4.12, T4.14, T4.16, T4.18, T4.70, T4.72, T4.74, U11.1 (3V_AUX), U11.10 (3V3), U11.21 (3V3), U11.32 (3V3), U11.38 (3V3), U11.56 (3V3), coutem.1
5VIN: C1.1, CN2.1, CN12a.A9, CN12a.B9, FAN2.2, Q1.4
5VINb: CN4.31, CN4.32, CN4b.17, CN4b.18
A5: CN12a.A5, R81.1
B5: CN12a.B5, R80.1
BTEN: R84.2, T2.54
BT_nDisable: JP2.2, Module1.91 (BT_nDisable)
CAM1_C_N: J5.8, Module1.127 (CAM1_C_N)
CAM1_C_P: J5.9, Module1.129 (CAM1_C_P)
CAM1_D0_N: J5.2, Module1.115 (CAM1_D0_N)
CAM1_D0_P: J5.3, Module1.117 (CAM1_D0_P)
CAM1_D1_N: J5.5, Module1.121 (CAM1_D1_N)
CAM1_D1_P: J5.6, Module1.123 (CAM1_D1_P)
CRF: C42#2.1, U12.14
Camera_GPIO: J5.11, Module1.97 (Camera_GPIO)
Ethernet_Pair0_N: CN15.10, Module1.10 (Ethernet_Pair0_N)
Ethernet_Pair0_P: CN15.11, Module1.12 (Ethernet_Pair0_P)
Ethernet_Pair1_N: CN15.5, Module1.6 (Ethernet_Pair1_N)
Ethernet_Pair1_P: CN15.4, Module1.4 (Ethernet_Pair1_P)
Ethernet_Pair2_N: CN15.2, Module1.9 (Ethernet_Pair2_N)
Ethernet_Pair2_P: CN15.3, Module1.11 (Ethernet_Pair2_P)
Ethernet_Pair3_N: CN15.9, Module1.5 (Ethernet_Pair3_N)
Ethernet_Pair3_P: CN15.8, Module1.3 (Ethernet_Pair3_P)
Ethernet_nLED2: Module1.17 (Ethernet_nLED2(3.3v)), R103.1
Ethernet_nLED3: Module1.15 (Ethernet_nLED3(3.3v)), R102.1
Ethgreen: CN15.19, R102.2
Ethyell: CN15.17, R103.2
FAN: CN17.2, Q3.3
FB: R90.1, R91.1, R93.1, U9.2
FBR: R90.2, R92.2
GLOBAL_EN: JP4.2, Module1.99 (Global_EN)
GND: C1.2, C2.2, C20.2, C22.2, C23.2, C24.2, C25.2, C26.2, C27.2, C28.2, C29.2, C30.2, C31.2, C32.2, C33.2, C34.2, C35.2, C36.2, C37.2, C38.1, C41.2, C42.2, C42#2.2, C43.2, C43#2.2, C44.2, C45.1, C46.2, C47.1, C83.2, C84.2, C85.2, C86.2, C92.2, C93.2, C94.1, C95.1, C101.1, C102.2, CN2.2, CN2.3, CN4.1, CN4.2, CN4b.1, CN4b.2, CN5.7, CN12a.A12, CN12a.B12, CN13.5, CN13.6, CN17.S1, CN17.S2, CP3.1, CP4.2, CP5.1, CP6.2, CP7.2, CP10.2, CP11.1, Cavin.1, Cout.2, Css.1, Ct.2, D8.2, D16.1, FAN2.1, FAN2.S1, FAN2.S2, IC1.8, IC1.9, IC1.10, IC1.13, J2.2, J2.5, J2.8, J2.11, J2.17, J2.SH, J3.2, J3.5, J3.8, J3.11, J3.17, J3.S1, J4.6, J5.1, J5.4, J5.7, J5.10, J15.6, J15.10, J15.C5, JP5.1, Module1.1 (GND), Module1.2 (GND), Module1.7 (GND), Module1.8 (GND), Module1.13 (GND), Module1.14 (GND), Module1.22 (GND), Module1.23 (GND), Module1.32 (GND), Module1.33 (GND), Module1.42 (GND), Module1.43 (GND), Module1.52 (GND), Module1.53 (GND), Module1.59 (GND), Module1.60 (GND), Module1.65 (GND), Module1.66 (GND), Module1.71 (GND), Module1.74 (GND), Module1.98 (GND), Module1.107 (GND), Module1.108 (GND), Module1.113 (GND), Module1.114 (GND), Module1.119 (GND), Module1.120 (GND), Module1.125 (GND), Module1.126 (GND), Module1.131 (GND), Module1.132 (GND), Module1.137 (GND), Module1.138 (GND), Module1.144 (GND), Module1.150 (GND), Module1.155 (GND), Module1.156 (GND), Module1.161 (GND), Module1.162 (GND), Module1.167 (GND), Module1.168 (GND), Module1.173 (GND), Module1.174 (GND), Module1.179 (GND), Module1.180 (GND), Module1.185 (GND), Module1.186 (GND), Module1.191 (GND), Module1.192 (GND), Module1.197 (GND), Module1.198 (GND), Q1.3, Q2.2, Q3.2, R2.1, R22.2, R23.2, R25.2, R27.2, R28.1, R29.1, R30.2, R36.2, R54.2, R55.2, R57.1, R74.1, R78.1, R80.2, R81.2, R82.1, R91.2, R95.2, R96.1, R153.1, R154.1, Rn1.2, SP1.3, T1.1, T1.3, T1.9, T1.15, T1.21, T1.27, T1.33, T1.39, T1.45, T1.51, T1.57, T1.71, T1.73, T1.75, T2.1, T2.7, T2.27, T2.33, T2.39, T2.45, T2.51, T2.57, T2.63, T2.69, T2.75, T2.S1, T2.S2, T3.3, T3.5, T3.11, T3.27, T3.33, T3.39, T3.45, T3.51, T3.57, T3.71, T3.73, T3.S1, T3.S2, T4.1, T4.3, T4.9, T4.15, T4.21, T4.27, T4.33, T4.39, T4.45, T4.51, T4.57, T4.71, T4.73, T4.75, U3.5, U3.10, U4.5, U5.2, U6.1, U7.2, U9.5, U9.7, U9.9, U10.8, U11.53 (GND), U11.65 (GND), U12.11, U12.24, U12.25, U12.37, USB2.4, coutem.2
GPIO2: CN4.5, CN4b.5, Module1.58 (GPIO2)
GPIO3: CN4.6, CN4b.6, Module1.56 (GPIO3)
GPIO4: CN4.7, CN4b.7, Module1.54 (GPIO4)
GPIO5: CN4.8, CN4b.8, Module1.34 (GPIO5)
GPIO7: CN4.9, CN4b.9, Module1.37 (GPIO7)
GPIO8: CN4.10, CN4b.10, Module1.39 (GPIO8)
GPIO9: CN4.11, CN4b.11, Module1.40 (GPIO9)
GPIO10: CN4.12, CN4b.12, Module1.44 (GPIO10)
GPIO11: CN4.13, CN4b.13, Module1.38 (GPIO11)
GPIO14: Module1.55 (GPIO14), SP1.1, U4.4
GPIO15: Module1.51 (GPIO15), SP1.2, U4.1
GPIO16: Module1.29 (GPIO16), Q3.1, R153.2
GPIO18: Module1.49 (GPIO18), U4.2, U4.3
GPIO23: Module1.47 (GPIO23), R152.1
GPIO_VDD: Module1.78 (GPIO_VREF(1.8v/3.3v_Input)), R100.2, R101.2
H5V: CP5.2, J2.18, J3.18, U6.2
HDMI0_CEC: J3.13, Module1.151 (HDMI0_CEC)
HDMI0_CLK_N: J3.12, Module1.190 (HDMI0_CLK_N)
HDMI0_CLK_P: J3.10, Module1.188 (HDMI0_CLK_P)
HDMI0_HOTPLUG: J3.19, Module1.153 (HDMI0_HOTPLUG)
HDMI0_SCL: J3.15, Module1.200 (HDMI0_SCL)
HDMI0_SDA: J3.16, Module1.199 (HDMI0_SDA)
HDMI0_TX0_N: J3.9, Module1.184 (HDMI0_TX0_N)
HDMI0_TX0_P: J3.7, Module1.182 (HDMI0_TX0_P)
HDMI0_TX1_N: J3.6, Module1.178 (HDMI0_TX1_N)
HDMI0_TX1_P: J3.4, Module1.176 (HDMI0_TX1_P)
HDMI0_TX2_N: J3.3, Module1.172 (HDMI0_TX2_N)
HDMI0_TX2_P: J3.1, Module1.170 (HDMI0_TX2_P)
HDMI1_CEC: J2.13, Module1.149 (HDMI1_CEC)
HDMI1_CLK_N: J2.12, Module1.166 (HDMI1_CLK_N)
HDMI1_CLK_P: J2.10, Module1.164 (HDMI1_CLK_P)
HDMI1_HOTPLUG: J2.19, Module1.143 (HDMI1_HOTPLUG)
HDMI1_SCL: J2.15, Module1.147 (HDMI1_SCL)
HDMI1_SDA: J2.16, Module1.145 (HDMI1_SDA)
HDMI1_TX0_N: J2.9, Module1.160 (HDMI1_TX0_N)
HDMI1_TX0_P: J2.7, Module1.158 (HDMI1_TX0_P)
HDMI1_TX1_N: J2.6, Module1.154 (HDMI1_TX1_N)
HDMI1_TX1_P: J2.4, Module1.152 (HDMI1_TX1_P)
HDMI1_TX2_N: J2.3, Module1.148 (HDMI1_TX2_N)
HDMI1_TX2_P: J2.1, Module1.146 (HDMI1_TX2_P)
HSD1+: U3.7, U12.31
HSD1-: U3.6, U12.30
HSD2+: CN13.3, U3.9
HSD2-: CN13.2, U3.8
N00030: CN13.1, R75.2
N00031: Q2.1, R152.2, R154.2
N00041: U5.4, U12.18
N00048: C32.1, R52.2, U12.33, X3.1
N00049: C34.1, R52.1, U12.32, X3.2
N00060: U5.1, USB2.1
N00074: D2.1, R3.1
N00076: D1.1, R4.1
N00079: CN1a.1, R76.1, R77.1, U4.7
N00080: CN1a.2, R76.2, R78.2, U4.6
N00089: D17.2, R56.1
N00091: D16.2, R7.1
N00092: R83.1, T3.6
N00093: C96.2, R93.2
N00094: C93.1, R94.2
N00095: R96.2, U7.5
N00099: C20.1, CN15.1, CN15.6, CN15.7, CN15.12
N00100: D18.2, R9.2
NJ001: Rg.2, U10.1
NJ_cmp: R94.1, U9.3
NJ_en: Q2.3, R88.1, U9.6
NJ_g: Q5.3, Rg.1
NJ_rt: R95.1, U9.4
NJ_sw: L1.2, U9.8
NONrm0: R53.2, U12.28
Nj002: CS.2, RS.2, U10.2
Nj003: CnB.1, RnB.2
Nj005: CnB.2, CnF.2, Rn1.1, Rn2.2, U10.5
Nj007: Q5.4, RS.1, Rsen.2
Nj008: D8.1, L2.1, Q5.1, Q5.2, Q5.5, Q5.6
Nj009: RnF.1, U10.6
Nj010: CnF.1, RnF.2
Nj011: Ct.1, U10.7
Njen: Ren.2, U10.4
Nonrm: R55.1, U12.22
PCIe_CLK_N: Module1.110 (PCIe_CLK_P), U11.47 (REFCLKN_IN)
PCIe_CLK_P: Module1.112 (PCIe_CLK_N), U11.46 (REFCLKP_IN)
PCIe_CLK_nREQ: Module1.102 (PCIe_CLK_nREQ), R107.1, T1.52
PCIe_RX_N: Module1.118 (PCIe_RX_N), U11.54 (TXP_IN)
PCIe_RX_P: Module1.116 (PCIe_RX_P), U11.55 (TXN_IN)
PCIe_TX_N: Module1.124 (PCIe_TX_N), U11.51 (RXP_IN)
PCIe_TX_P: Module1.122 (PCIe_TX_P), U11.52 (RXN_IN)
PCIe_nRST: Module1.109 (PCIe_nRST), U11.3 (RES_IN)
PI_LED_nPWR: JP3.2, Module1.95 (nPI_LED_PWR)
PLLF: C43.1, U12.34
Pi_nLED_Activity: D17.1, Module1.21 (PI_nLED_Activity)
RBi: R54.1, U12.35
RSTO: CN5.4, T1.50, T2.52, T4.50, U11.2 (RES_OUT)
SCL0: CN4.4, CN4b.3, J5.13, Module1.80 (SCL0)
SDA0: CN4.3, CN4b.4, J5.14, Module1.82 (SDA0)
SD_CLK: J4.5, Module1.57 (SD_CLK)
SD_CMD: J4.3, Module1.62 (SD_CMD)
SD_DAT0: J4.7, Module1.63 (SD_DAT0)
SD_DAT1: J4.8, Module1.67 (SD_DAT1)
SD_DAT2: J4.1, Module1.69 (SD_DAT2)
SD_DAT3: J4.2, Module1.61 (SD_DAT3)
SD_PWR: J4.4, U7.6
SD_PWR_ON: Module1.75 (SD_PWR_ON), R97.1, U7.3
SIM_DATE: C86.1, J15.C7, T3.34
SIM_PWR: C83.1, J15.C1, T3.36
SIM_RST: C84.1, J15.C2, T3.30
SIM_SLK: C85.1, J15.C3, T3.32
SIM_SW: R82.2, T3.60
USB1+: T3.7, U12.2
USB1-: T3.9, U12.1
USB2+: T2.3, U12.4
USB2-: T2.5, U12.3
USB3+: U12.7, USB2.3
USB3-: U12.6, USB2.2
USB4+: R105x.1, U12.9
USB4-: R106x.1, U12.8
USBD5+: CN4.21, CN4b.16, R105x.2
USBD5-: CN4.20, CN4b.15, R106x.2
USB_N: Module1.103 (USB2_N), U3.4
USB_OTG_ID: Module1.101 (USB_OTG_ID), R74.2, R75.1, U3.2
USB_P: Module1.105 (USB2_P), U3.3
VCC: CP7.1, Module1.84 (+3.3v_(Output)), Module1.86 (+3.3v_(Output)), R97.2, R100.1, U7.1
VCC-2: C95.2, CN17.1, CP4.1, CS.1, D1.2, D2.2, IC1.1, IC1.2, Module1.77 (+5v_(Input)), Module1.79 (+5v_(Input)), Module1.81 (+5v_(Input)), Module1.83 (+5v_(Input)), Module1.85 (+5v_(Input)), Module1.87 (+5v_(Input)), Q1.1, Q1.2, Q1.5, Q1.6, R77.2, R88.2, Ravin.2, Ren.1, Rsen.1, U5.5, U6.3, U9.1, U10.3, pg.2
WLANEN: R85.2, T2.56
WL_nDisable: JP1.2, Module1.89 (WL_nDisable)
WWAN_LED: D18.1, T3.10
fclk1+: T4.53, U11.18 (REFCLKP_1)
fclk1-: T4.55, U11.19 (REFCLKN_1)
fclk2+: CN5.2, U11.27 (REFCLKP_2)
fclk2-: CN5.3, U11.28 (REFCLKN_2)
fclk3+: T1.55, U11.44 (REFCLKP_3)
fclk3-: T1.53, U11.45 (REFCLKN_3)
fclk4+: T2.47, U11.62 (REFCLKP_4)
fclk4-: T2.49, U11.63 (REFCLKN_4)
h003: R33.2, U11.4 (GPIO_0)
h004: R23.1, U11.5 (GPIO_2)
h005: R22.1, U11.8 (GPIO_4)
h012: R30.1, U11.16 (REXT1)
h025: R26.2, U11.30 (GPIO_5)
h026: R24.2, U11.31 (GPIO_1)
h027: R27.1, U11.33 (TEST_EN)
h028: R29.2, U11.34 (GPIO_3)
h029: R25.1, U11.35 (GPIO_6)
h030: R28.2, U11.36 (GPIO_7)
m002: Cavin.2, IC1.3, IC1.5, Ravin.1
m003: IC1.4, pg.1
m3das: D19.1, T1.10
m004: Css.2, IC1.6
m005: C11.1, IC1.7, R1.1, R2.2
m006: IC1.11, IC1.12, L11.1
nEXTRST: Module1.100 (nEXTRST), U12.26
nRPIBOOT: JP5.2, Module1.93 (nRPIBOOT)
rext2: R36.1, U11.49 (REXT2)
rx1+: T4.41, U11.13 (RXP_1)
rx1-: T4.43, U11.14 (RXN_1)
rx2+: CN5.9, U11.24 (RXP_2)
rx2-: CN5.8, U11.25 (RXN_2)
rx3+: T1.43, U11.41 (RXP_3)
rx3-: T1.41, U11.42 (RXN_3)
rx4+: T2.41, U11.59 (RXP_4)
rx4-: T2.43, U11.60 (RXN_4)
tx1+: C52.2, U11.11 (TXP_1)
tx1-: C53.2, U11.12 (TXN_1)
tx1c+: C52.1, T4.47
tx1c-: C53.1, T4.49
tx2+: C54.2, U11.22 (TXP_2)
tx2-: C55.2, U11.23 (TXN_2)
tx2c+: C54.1, CN5.6
tx2c-: C55.1, CN5.5
tx3+: C56.2, U11.39 (TXP_3)
tx3-: C57.2, U11.40 (TXN_3)
tx3c+: C56.1, T1.49
tx3c-: C57.1, T1.47
tx4+: C58.2, U11.57 (TXP_4)
tx4-: C59.2, U11.58 (TXN_4)
tx4c+: C58.1, T2.35
tx4c-: C59.1, T2.37

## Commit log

2024-12-28 Add files via upload
    回路図をupしました
2024-12-28 Update README.md
    boot CM5 via NVMe behind PCIe switch
